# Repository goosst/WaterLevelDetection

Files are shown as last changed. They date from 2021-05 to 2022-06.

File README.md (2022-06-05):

# WaterLevelDetection

- [WaterLevelDetection](#waterleveldetection)
  * [Goal](#goal)
  * [Wishlist](#wishlist)
  * [Concept and used components](#concept-and-used-components)
    + [Controller](#controller)
    + [Pressure sensing and power electronics](#pressure-sensing-and-power-electronics)
  * [Implementation](#implementation)
    + [List of components](#list-of-components)
    + [Power electronics](#power-electronics)
    + [Current measurement](#current-measurement)
  * [Calibration](#calibration)
  * [Pictures](#pictures)
  * [Home assistant integration](#home-assistant-integration)
  * [(Possible) next steps](#-possible--next-steps)

## Goal

Measure the level of available water in a rainwater well and report in a home automation tool (here home assitant).

Spoiler alert: a 4-20mA, 24V converter using an ESP8266 was created for this.

## Wishlist

- Report level of water depth over WiFi (mqtt messages) 
- Since waterlevel only needs to be measured every x hours or days, use a deepsleep method to safe power and prevent heating / wear of components
- Use common components (through hole components for electronics, no SMD, ... )
- Be able to update software over the air

## Concept and used components

The measuring principle is based on water pressure, the pressure at the bottom of the well is proportional with the height of the water. Other methods using distance sensors sound quite unreliable (reflections, need to have a wide cone of free air to measure to the bottom of the well, ... ) or cumbersome (capacitive sensing).

### Controller
To take care of the Wifi and mqtt messages, an ESP8266 ([Wemos D1 mini](https://www.banggood.com/Geekcreit-D1-mini-V2_2_0-WIFI-Internet-Development-Board-Based-ESP8266-4MB-FLASH-ESP-12S-Chip-p-1143874.html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)) is used.

### Pressure sensing and power electronics
The sensor used here: [Pressure sensor](https://www.banggood.com/Submersible-Water-Level-Transmitter-Level-Transducer-Sensor-0-5mH2O-6m-Cable-p-1146896.html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).

This sensor creates an additional challenge, it returns a current between 4-20mA - proportional with the pressure - and requires a 24V supply voltage. 

- To measure the 4-20 mA, an INA219 sensor is used. This is a high side current sensor and additionally measures the bus voltage. This voltage will be used later to generate a reliable supply voltage.
- I was not able to identify a boost DC-DC converter that was through-hole (not SMD) and had an enable/disable pin. So I've decided to create a small dc-converter myself. It's important to use an N-channel mosfet which can be switched by a 3.3V signal from the ESP8266. All the rest (diode, inductor, capacitor) are quite standard components which you can find cheaply.
Other attempts made with breakoutboards using MT3608's, didn't really produce a stable output voltage when  component temperature got warmer etc.

## Implementation

Only the conceptual implementation is explained here, the source files contain the details.
<!-- ![conceptual implementation](concept.svg) -->
Concept 4-20mA

<!-- {{< figure src="concept.svg" title="PCB water level" height="200">}} -->

### List of components
| Components used      | 
| :------------- | 
|  [Wemos D1 mini](https://www.banggood.com/Geekcreit-D1-mini-V2_2_0-WIFI-Internet-Development-Board-Based-ESP8266-4MB-FLASH-ESP-12S-Chip-p-1143874.html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)| 
| [Pressure sensor](https://www.banggood.com/Submersible-Water-Level-Transmitter-Level-Transducer-Sensor-0-5mH2O-6m-Cable-p-1146896.html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) | 
| INA219: [example](https://nl.aliexpress.com/item/4000330275495.html?spm=a2g0s.9042311.0.0.28c74c4d10PHbJ) |
| N-channel mosfet switchable by 3.3V digital signal: example FQP30N06L |
| inductor, diode, capacitor, terminal |
| BMP280: to measure air pressure |

### Power electronics

- To reliably create the supply voltage for the pressure sensor (~24V), a feedback mechanism is used:
  - the INA219 sends the actual measured voltage over I2C to the wemos
  - in the Wemos a feedback loop (PI controller) adjusts the duty ratio of the mosfet, this guarantees a constant voltage over temperature etc. and doesn't require a consistent input supply voltage.
- Pin D8 of the WEMOS has to be used to generate the PWM signal for the dc-converter, when going to deepsleep this pin is inherently pulled down and the converter stops switching safely

A prototype pcb was created for it (with an additional - in the end unused - MAX417 current sensor), but the complexity is not very high to just solder it on a board ... .

### Current measurement
Typical breakout boards using the INA219, come with a 0.1 Ohm shunt resistor.
Only 4-20 mA is produced by the sensor, this means the voltage measured over the shunt would only be 0.4-2 mV which is basically noise ... .
According the datasheet, the range of the INA219 can be configured from 40 to 320mV, hence a resistor in the range of 2 to 15 Ohm would be acceptable. Here, a resistor of 10 Ohm is used.

<!-- ![resistor desoldering](pictures/INA219.png) -->
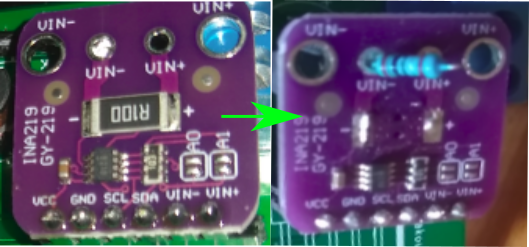
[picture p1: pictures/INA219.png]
INA 219


## Calibration

Now the hardware is setup, a calibration was done to correlate the measured shunt voltage / current with the pressure.
I've inserted the pressure sensor in water and came to this table:

| Level (meter) | Shunt voltage mV | shunt current mA |
| :--- | :---: | ---: |
|  0 (air) | 51 | 5.1 |
| 1 | 85 | 8.5 | 
| 1.5 | 99 | 9.9 | 

Luckily this leads to a linear trend :)

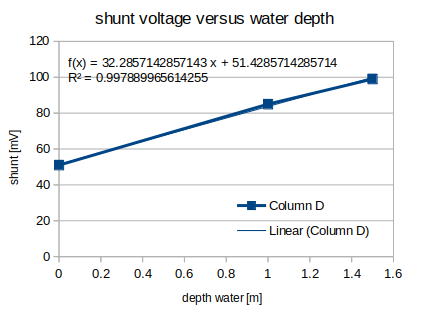
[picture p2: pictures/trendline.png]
trend line


### Update May 2022

- Connected an additional cheap air pressure sensor BMP280 pressure sensor to the ESP (over i2c).
- moved further calculation of waterheight to a little python script triggered by home assistant

## Pictures

PCB board used (here with additional options for prototyping, the resistor of course gets replaced by the pressure sensor)
<!-- ![](pictures/PCB.jpg) -->
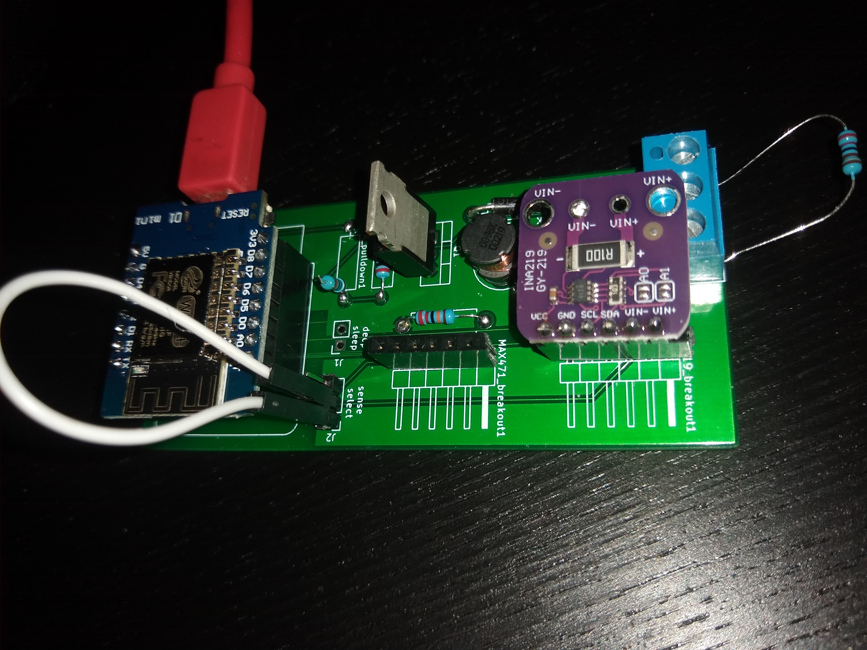
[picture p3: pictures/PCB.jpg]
PCB


Looks of the pressure sensor:
<!-- ![](pictures/sensor.jpg) -->
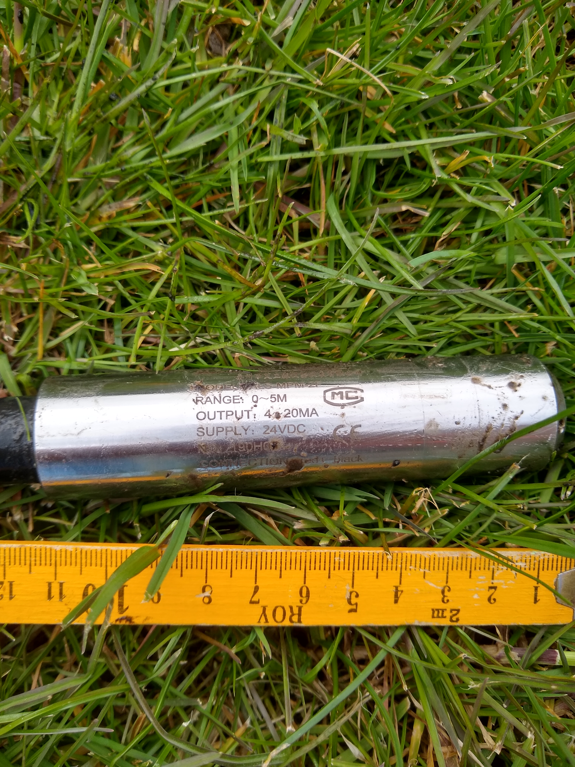
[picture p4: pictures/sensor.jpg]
pressure sensor


Connections around the well are embedded in a two-component silicone gel:
<!-- ![](pictures/potting.jpg) -->
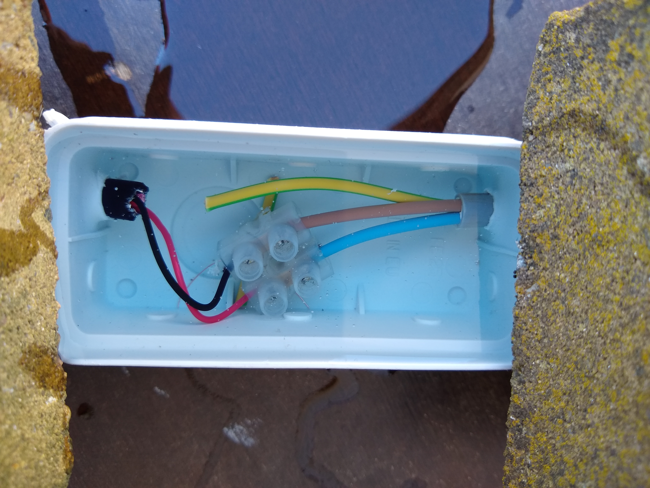
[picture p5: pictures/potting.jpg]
potting


## Home assistant integration

a few mqtt topics were defined to read out and visualize the data:
```
  - platform: mqtt
    name: "Water level depth"
    state_topic: /sensor/WEMOSD1-14269530/data/waterdepth
    expire_after: 864000
    unit_of_measurement: "m"
    payload_available: "Online"
    payload_not_available: "water level sensor offline"
```
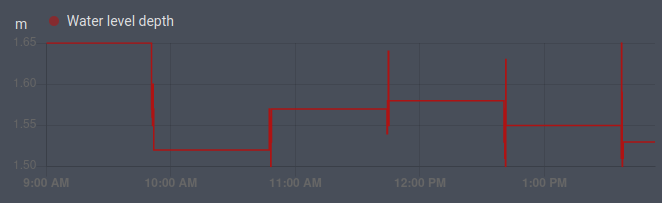
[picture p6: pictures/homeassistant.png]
water level home assistant


## (Possible) next steps

- optimize Kicad files (they work but there are additional items added for debugging purposes)
  - remove incorrect R_pulldown1 (or don't connect when using it)
  - remove place for redundant component (MAX 417 and related jumpers)
- create a proper 4-20mA, 24V converter using SMD components and compact converters

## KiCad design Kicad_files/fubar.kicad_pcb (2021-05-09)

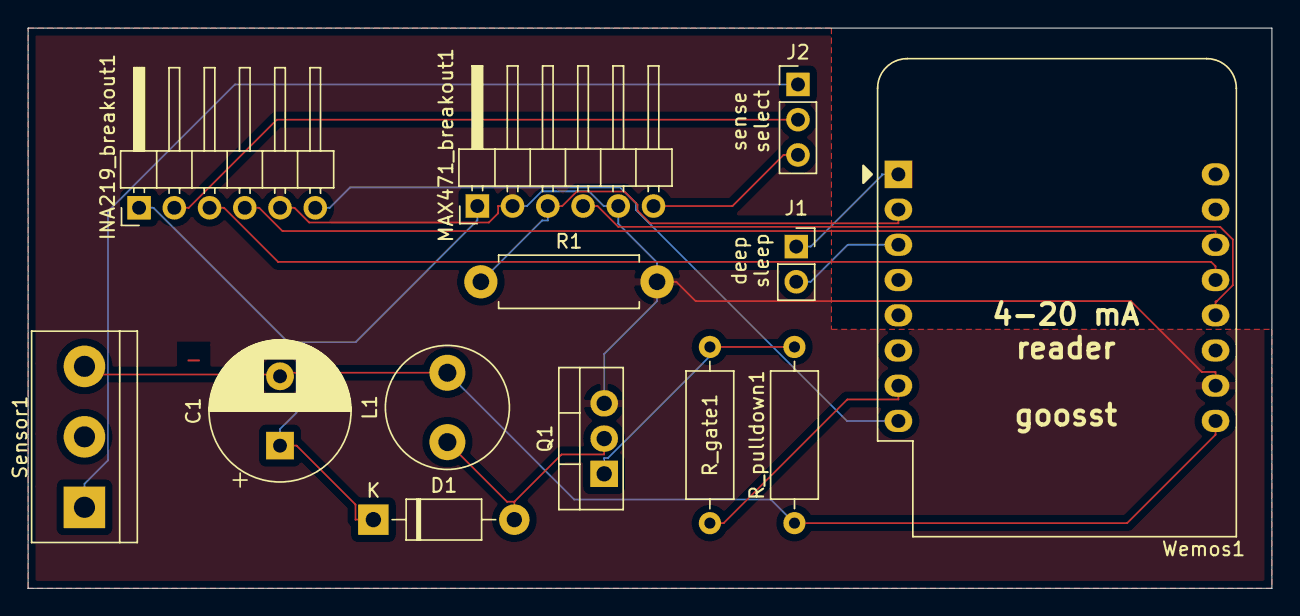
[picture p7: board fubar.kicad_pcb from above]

Board: 2 copper layers, 89.7 x 40.4 mm, 13 parts (0 on the bottom side), 16 nets.

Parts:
C1: CP; CP_Radial_D10.0mm_P5.00mm
D1: 1N5817; D_DO-41_SOD81_P10.16mm_Horizontal
INA219_breakout1: Conn_01x06_Female; PinHeader_1x06_P2.54mm_Horizontal
J1: Conn_01x02_Female; PinSocket_1x02_P2.54mm_Vertical
J2: select_sensing; PinHeader_1x03_P2.54mm_Vertical
L1: L_Core_Ferrite; L_Radial_D8.7mm_P5.00mm_Fastron_07HCP
MAX471_breakout1: Conn_01x06_Female; PinHeader_1x06_P2.54mm_Horizontal
Q1: IRLZ44N; TO-220-3_Vertical
R1: 200k; R_Axial_DIN0411_L9.9mm_D3.6mm_P12.70mm_Horizontal
R_gate1: 200; R_Axial_DIN0309_L9.0mm_D3.2mm_P12.70mm_Horizontal
R_pulldown1: 10k; R_Axial_DIN0309_L9.0mm_D3.2mm_P12.70mm_Horizontal
Sensor1: Screw_Terminal_01x03; TerminalBlock_bornier-3_P5.08mm
Wemos1: WeMos_D1_mini; WEMOS_D1_mini_light

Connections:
+3V3: INA219_breakout1.6, Wemos1.8
+5V: C1.2, L1.2, R_pulldown1.1, Sensor1.3, Wemos1.9
/A0: MAX471_breakout1.3, R1.1, Wemos1.2
/D0: J1.2, Wemos1.3
/D3: MAX471_breakout1.4, Wemos1.12
/D8: R_gate1.2, Wemos1.7
/RST: J1.1, Wemos1.1
/SCL: INA219_breakout1.4, Wemos1.14
/SDA: INA219_breakout1.3, Wemos1.13
/Vdc_out_plus: C1.1, D1.1, INA219_breakout1.1, MAX471_breakout1.1
/Vshunt_INA219: INA219_breakout1.2, J2.2
/Vshunt_MAX417: J2.3, MAX471_breakout1.6
/Vshunt_select: J2.1, Sensor1.1
GNDREF: INA219_breakout1.5, MAX471_breakout1.2, MAX471_breakout1.5, Q1.3, R1.2, Wemos1.10
unnamed: D1.2, L1.1, Q1.2
unnamed: Q1.1, R_gate1.1, R_pulldown1.2

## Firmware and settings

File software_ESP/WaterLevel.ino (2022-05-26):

// 6 dec 2020, basic open loop duty ratio
//              structured using very basic task scheduling: https://github.com/sskata/Arduino-Task-Scheduling-Template/blob/master/TaskSchedulingTemplate_v1.0.ino
// 2-3 may 2021: added functions for PI controller, OTA, mqtt, deepsleep
// 26 may 2022: added BMP280 pressure sensor over i2c

#include <Wire.h>
#include <INA219_WE.h> //https://github.com/wollewald/INA219_WE
#include <ESP8266WiFi.h>  //For ESP8266
#include <PubSubClient.h> //For MQTT
#include <ESP8266mDNS.h>  //For OTA
#include <WiFiUdp.h>      //For OTA
#include <ArduinoOTA.h>   //For OTA
#include "configuration.h" // to store passwords of mqtt and wifi
#include <BMx280I2C.h>

//Set to 1 if tasks with respective period is used, otherwise set to 0 to save memory and CPU
#define TASK_2MS 1
#define TASK_200MS 1
#define TASK_10000MS 1

#define Deepsleep 1
unsigned int sleepSeconds = 3600; //seconds to stay in deepsleep (i.e. period wakups, max of ~71 minutes)
const uint32_t deepsleepmicroseconds = sleepSeconds * 1000000;

float voltage_setp_dcdc=20; //setpoint for voltage over output terminals

//mqtt
String mqtt_client_id = "WEMOSD1-"; //This text is concatenated with ChipId to get unique client_id
String mqtt_base_topic = "/sensor/" + mqtt_client_id + "/data";
#define shunt_topic "/shuntvolt"
#define voltage_topic "/voltage"
#define dutyratio_topic "/dutr"
#define waterdepth_topic "/waterdepth"
#define airpressure_topic "/airpress"

#define I2C_ADDRESS 0x40
INA219_WE ina219(I2C_ADDRESS);

const byte D_DCDC = 15; //pin D8 on wemos D1 generates PWM for dc-converter, pin8 makes it feasible to send out zero when going in deep sleep

#define I2C_ADDRESS_BMP 0x76
//create a BMx280I2C object using the I2C interface with I2C Address 0x76
BMx280I2C bmx280(I2C_ADDRESS_BMP);

//structure for PI controller
struct PI_ctrl {
  float Kp;
  float Ti;
  float mem1;
  float mem2;
  float output;
  float samplingtime;
};
struct PI_ctrl PI_DC;


//MQTT client
WiFiClient espClient;
PubSubClient mqtt_client(espClient);

//Necesary to make Arduino Software autodetect OTA device
WiFiServer TelnetServer(8266);

void setup()
{

  Serial.begin(9600);

  setup_wifi();

  //OTA things
  Serial.print("Configuring OTA device...");
  TelnetServer.begin();   //Necesary to make Arduino Software autodetect OTA device
  ArduinoOTA.onStart([]() {
    Serial.println("OTA starting...");
  });
  ArduinoOTA.onEnd([]() {
    Serial.println("OTA update finished!");
    Serial.println("Rebooting...");
  });
  ArduinoOTA.onProgress([](unsigned int progress, unsigned int total) {
    Serial.printf("OTA in progress: %u%%\r\n", (progress / (total / 100)));
  });
  ArduinoOTA.onError([](ota_error_t error) {
    Serial.printf("Error[%u]: ", error);
    if (error == OTA_AUTH_ERROR) Serial.println("Auth Failed");
    else if (error == OTA_BEGIN_ERROR) Serial.println("Begin Failed");
    else if (error == OTA_CONNECT_ERROR) Serial.println("Connect Failed");
    else if (error == OTA_RECEIVE_ERROR) Serial.println("Receive Failed");
    else if (error == OTA_END_ERROR) Serial.println("End Failed");
  });
  ArduinoOTA.begin();
  Serial.println("OTA OK");

  Serial.println("Configuring MQTT server...");
  mqtt_client_id = mqtt_client_id + ESP.getChipId();
  mqtt_base_topic = "/sensor/" + mqtt_client_id + "/data";
  mqtt_client.setServer(mqtt_server, 1883);
  Serial.printf("   Server IP: %s\r\n", mqtt_server);
  Serial.printf("   Username:  %s\r\n", mqtt_user);
  Serial.println("   Cliend Id: " + mqtt_client_id);
  Serial.println("   MQTT configured!");

  Serial.println("Setup completed! Running app...");

  // PI controller for voltage regulation
  PI_DC.Kp = 0.25;
  PI_DC.Ti = 2;
  PI_DC.mem1 = 0;
  PI_DC.mem2 = 0;
  PI_DC.output = 0;
  PI_DC.samplingtime = 0.2;


  pinMode(LED_BUILTIN, OUTPUT);
  analogWriteFreq(1000); //PWM frequency dc converter

  Wire.begin();
  if (!ina219.init()) {
    Serial.println("INA219 not connected!");
  }
  else {

    ina219.setADCMode(BIT_MODE_12);
    ina219.setMeasureMode(TRIGGERED);

    /* Set PGain
      Gain *  * Shunt Voltage Range *   * Max Current
      PG_40       40 mV                    0,4 A
      PG_80       80 mV                    0,8 A
      PG_160      160 mV                   1,6 A
      PG_320      320 mV                   3,2 A (DEFAULT)
    */
    ina219.setPGain(PG_320);

    /* Set Bus Voltage Range
      BRNG_16   -> 16 V
      BRNG_32   -> 32 V (DEFAULT)
    */
    // ina219.setBusRange(BRNG_32); // choose range and uncomment for change of default

    Serial.println("INA219 Current Sensor Example Sketch - Triggered Mode");
  }

  //begin() checks the Interface, reads the sensor ID (to differentiate between BMP280 and BME280)
  //and reads compensation parameters.
  if (!bmx280.begin())
  {
    Serial.println("begin() failed. check your BMx280 Interface and I2C Address.");
    while (1);
  }

  if (bmx280.isBME280())
    Serial.println("sensor is a BME280");
  else
    Serial.println("sensor is a BMP280");

  //reset sensor to default parameters.
  bmx280.resetToDefaults();

  //by default sensing is disabled and must be enabled by setting a non-zero
  //oversampling setting.
  //set an oversampling setting for pressure and temperature measurements. 
  bmx280.writeOversamplingPressure(BMx280MI::OSRS_P_x16);
  bmx280.writeOversamplingTemperature(BMx280MI::OSRS_T_x16);

  //if sensor is a BME280, set an oversampling setting for humidity measurements.
  if (bmx280.isBME280())
    bmx280.writeOversamplingHumidity(BMx280MI::OSRS_H_x16);
  
}



struct INAvar {
  float busVoltage_V;
  float current_mA;
  float shuntVoltage_mV;
};
struct INAvar SensorMeas;
int counterloops = 0; //loops of slowest task rate before entering deepsleep
float voltage_zeroDR = 0; // voltage Vout-esp_ground at duty ratio of zero
bool first_run = true;

////////////////////////////////////////////////
// start of main loop
////////////////////////////
void loop()
{ //Task scheduler, schedules and executes tasks
  ArduinoOTA.handle();

#if TASK_2MS
  static long unsigned int a = micros();
  if (micros() >= (a + 2000)) { //2 ms tasks
    a = micros();
    /* Tasklist: 2 ms */

  }
  else if (micros() < a) a = 0;
#endif

#if TASK_200MS
  static long unsigned int f = micros();
  if (micros() >= (f + 200000)) { //200 ms tasks
    f = micros();
    /* Tasklist: 500 ms */
    //    firstTask();

    if (first_run) //get voltage on bus when converter is inactive
    {
      ctrl_DCDC(0);
    }

    SensorMeas = read_INA219();

    if (first_run) //get voltage on bus when converter is inactive
    {
      voltage_zeroDR = SensorMeas.busVoltage_V;
      first_run = false;
    }


//    Serial.print("struct Shunt Voltage [mV]: "); Serial.println(SensorMeas.shuntVoltage_mV);
//    Serial.print("struct bus Voltage [V]: "); Serial.println(SensorMeas.busVoltage_V);
//    Serial.print("struct current_mA: "); Serial.println(SensorMeas.current_mA); //not relevant when replacing resistor

    float setp_volt_out = voltage_setp_dcdc + voltage_zeroDR;
//    Serial.print("setp_volt_out: "); Serial.println(setp_volt_out);

    PI_DC = PI_loop(PI_DC, SensorMeas.busVoltage_V, setp_volt_out);


    //clip maximum duty ratio
    if (PI_DC.output > 30) {
      PI_DC.output = 30;
    }
    if (PI_DC.output < 0) {
      PI_DC.output = 0;
    }

    ctrl_DCDC((int)(PI_DC.output));
    Serial.print("PI_DC output: "); Serial.println(PI_DC.output);

    //    ctrl_DCDC(0);
    blinkLED();



  }
  else if (micros() < f) f = 0;
#endif

#if TASK_10000MS
  static long unsigned int g = micros();
  if (micros() >= (g + 10000000)) { 
    g = micros();
    /* Tasklist: 10000 ms */

      //start a pressure measurement
  if (!bmx280.measure())
  {
    Serial.println("could not start measurement, is a measurement already running?");
    return;
  }

    if (!mqtt_client.connected())
    {
      mqtt_reconnect();
    }
    mqtt_client.loop();

      //wait for the pressure measurement to finish
  do
  {
    delay(100);
  } while (!bmx280.hasValue());

//  Serial.print("Pressure: "); Serial.println(bmx280.getPressure());
//  Serial.print("Pressure (64 bit): "); Serial.println(bmx280.getPressure64());
//  Serial.print("Temperature: "); Serial.println(bmx280.getTemperature());

  //important: measurement data is read from the sensor in function hasValue() only. 
  //make sure to call get*() functions only after hasValue() has returned true. 
  if (bmx280.isBME280())
  {
    Serial.print("Humidity: "); 
    Serial.println(bmx280.getHumidity());
  }

    //    Serial.print("mqtt voltage V: ");
    //    Serial.println(SensorMeas.busVoltage_V);
    //    Serial.print("mqtt current shunt mA: ");
    //    Serial.println(SensorMeas.current_mA);
    //    Serial.println(String(SensorMeas.busVoltage_V,3).c_str());
    
        float waterdepth=0.030908096*SensorMeas.shuntVoltage_mV-1.5878; //convert shunt to waterdepth based on calibration of sensor

    
    mqtt_client.publish((mqtt_base_topic + shunt_topic).c_str(), String(SensorMeas.shuntVoltage_mV, 2).c_str(), true);
    mqtt_client.publish((mqtt_base_topic + voltage_topic).c_str(), String(SensorMeas.busVoltage_V, 2).c_str(), true);
    mqtt_client.publish((mqtt_base_topic + dutyratio_topic).c_str(), String(PI_DC.output, 2).c_str(), true);
    mqtt_client.publish((mqtt_base_topic + airpressure_topic).c_str(), String(bmx280.getPressure64(), 2).c_str(), true);
    mqtt_client.publish((mqtt_base_topic + waterdepth_topic).c_str(), String(waterdepth, 2).c_str(), true);


#if Deepsleep
    if (counterloops > 6)
    {
      ESP.deepSleep(deepsleepmicroseconds);
    }
    counterloops = counterloops + 1;
#endif


  }
  else if (micros() < g) g = 0;
#endif


}

////////////////////////////
// end of main loop
/////////////////////////////////////////////////////////////




bool LedStateRequest = true;
void blinkLED()
{
  digitalWrite(LED_BUILTIN, LedStateRequest);
  LedStateRequest = !LedStateRequest;
}


void ctrl_DCDC(float percentage)
{
  //duty ratio in percentage to PWM signal
  int value = 0.01 * percentage * 1024;
  analogWrite(D_DCDC, value);

}



struct INAvar read_INA219() {
  //read sensor data from INA 219 and report back in structure
  struct INAvar INAnow;

  float shuntVoltage_mV = 0.0;
  float loadVoltage_V = 0.0;
  float busVoltage_V = 0.0;
  float current_mA = 0.0;
  float power_mW = 0.0;
  bool ina219_overflow = false;

  ina219.startSingleMeasurement(); // triggers single-shot measurement and waits until completed
  shuntVoltage_mV = ina219.getShuntVoltage_mV();
  busVoltage_V = ina219.getBusVoltage_V();
//  current_mA = ina219.getCurrent_mA(); //not relevant when replacing 0.1ohm resistance
  //  power_mW = ina219.getBusPower();
  //  loadVoltage_V  = busVoltage_V + (shuntVoltage_mV/1000);
  ina219_overflow = ina219.getOverflow();

  //    Serial.print("Shunt Voltage [mV]: "); Serial.println(shuntVoltage_mV);
  //    Serial.print("Bus Voltage [V]: "); Serial.println(busVoltage_V);
  //    Serial.print("Load Voltage [V]: "); Serial.println(loadVoltage_V);
  //    Serial.print("Current[mA]: "); Serial.println(current_mA);
  //  Serial.print("Bus Power [mW]: "); Serial.println(power_mW);

  INAnow.busVoltage_V = busVoltage_V;
  INAnow.current_mA = current_mA;
  INAnow.shuntVoltage_mV = shuntVoltage_mV;
  return INAnow;
}



struct PI_ctrl PI_loop(struct PI_ctrl PI_in, float measurement, float setpoint) {
  struct PI_ctrl PI_out;
  float c0 = 0;
  float c1 = 0;
  float error = 0;
  float Ut1 = 0;
  float Et1 = 0;

  PI_out = PI_in;

  c0 = PI_in.Kp * (1 + PI_in.samplingtime / PI_in.Ti);
  c1 = -PI_in.Kp;

  Ut1 = PI_in.mem1;
  Et1 = PI_in.mem2;

  //anti-reset windup back clamping
  Et1 = Et1 + (PI_in.output - Ut1) / c0;
  Ut1 = PI_in.output;

  error = setpoint - measurement;
  PI_out.output = Ut1 + c0 * error + c1 * Et1;

  PI_out.mem1 = PI_out.output;
  PI_out.mem2 = error;

  return PI_out;

  //  struct PI_ctrl{
  //  float Kp;
  //  float Ti;
  //  float mem1;
  //  float mem2;
  //  float output;
  //  float samplingtime;
  //}
}



void mqtt_reconnect()
{
  // Loop until we're reconnected
  while (!mqtt_client.connected())
  {
    Serial.print("Attempting MQTT connection...");
    // Attempt to connect
    // If you do not want to use a username and password, change next line to
    // if (client.connect("ESP8266Client")) {
    if (mqtt_client.connect(mqtt_client_id.c_str(), mqtt_user, mqtt_password))
    {
      Serial.println("connected");
    } else
    {
      Serial.print("failed, rc=");
      Serial.print(mqtt_client.state());
      Serial.println(" try again in 5 seconds");
      // Wait 5 seconds before retrying
      delay(5000);
    }
  }
}


void setup_wifi()
{
  delay(10);
  Serial.print("Connecting to ");
  Serial.print(wifi_ssid);
  WiFi.begin(wifi_ssid, wifi_password);
  while (WiFi.status() != WL_CONNECTED) {
    delay(500);
    Serial.print(".");
  }
  Serial.println("OK");
  Serial.print("   IP address: ");
  Serial.println(WiFi.localIP());
}

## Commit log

2021-05-08 initial documentation and ESP8266 files for waterlevel detection
    [configuration_dummy.h]
2021-05-09 added kicad files prototype
    [DC_Converter.sch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]
2022-05-26 added BMP280 air pressure sensor
2022-05-26 merged missing items (basic waterdepth calculation)
    [WaterLevel.ino]
